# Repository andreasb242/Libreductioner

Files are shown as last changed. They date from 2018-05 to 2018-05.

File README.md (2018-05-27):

# Libreductioner
Induction loop sender for mower.

Tested and working with Landroid Worx. All Bugs in the Board are corrected with Version 1.1, all additional, no-needed Parts are removed.

# Forum Thread
Mikrocontroller.net: https://www.mikrocontroller.net/topic/451337 (German)

# Extension / Support for other mower
If you have another mower, or would like to improve the Board: Create a Pull request!

## Board / Circuit
The Board / Circuit is created with KiCad.

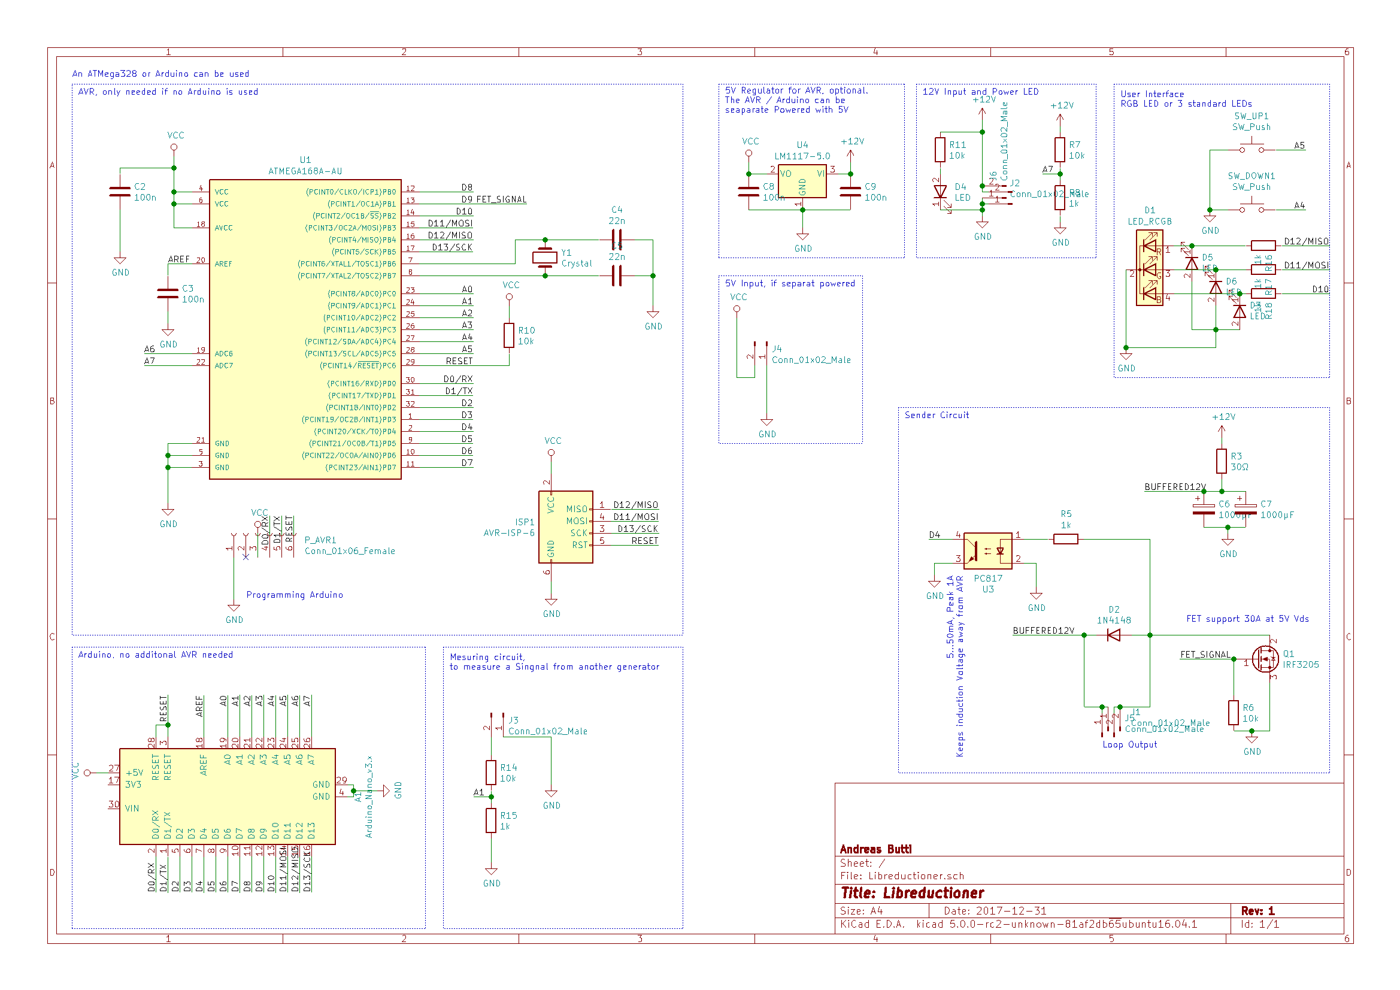
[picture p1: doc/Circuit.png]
Circuit

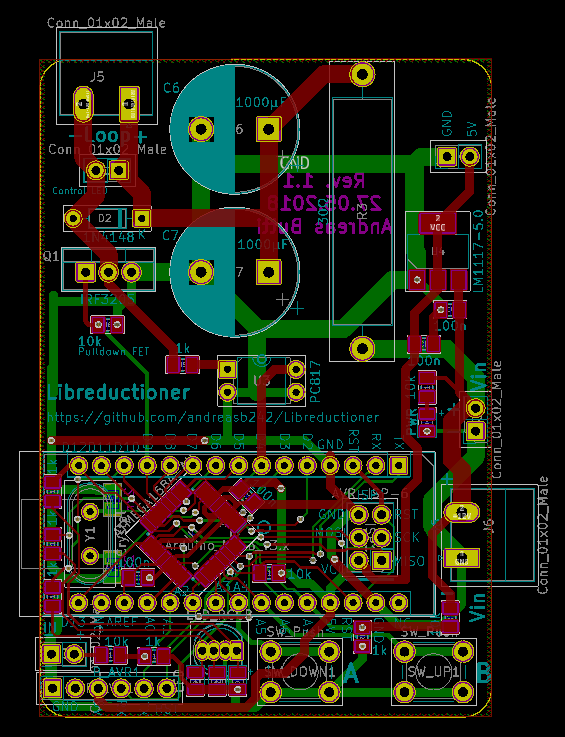
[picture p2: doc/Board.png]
Board

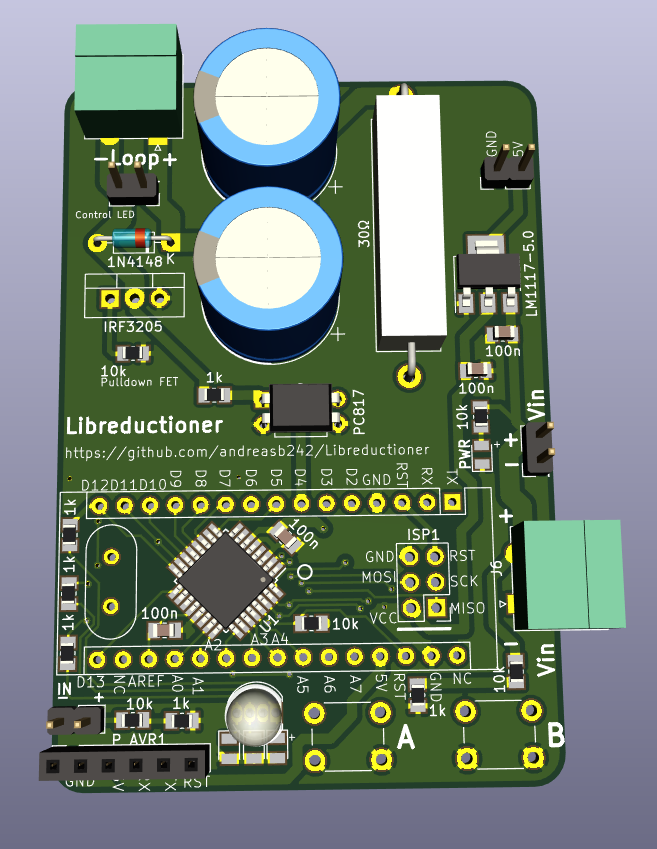
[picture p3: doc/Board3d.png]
Board


## Supported Mower
Currently working is the Landroid Worx

## Measuring
The Signal can be measured with a coil of a 24V Relais

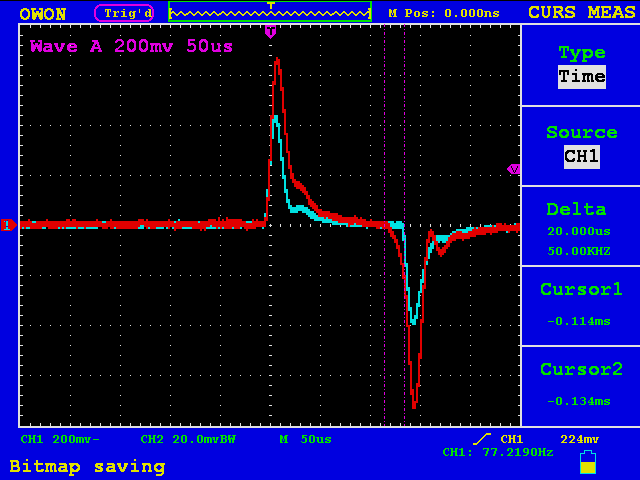
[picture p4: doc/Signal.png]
Signal Screenshot


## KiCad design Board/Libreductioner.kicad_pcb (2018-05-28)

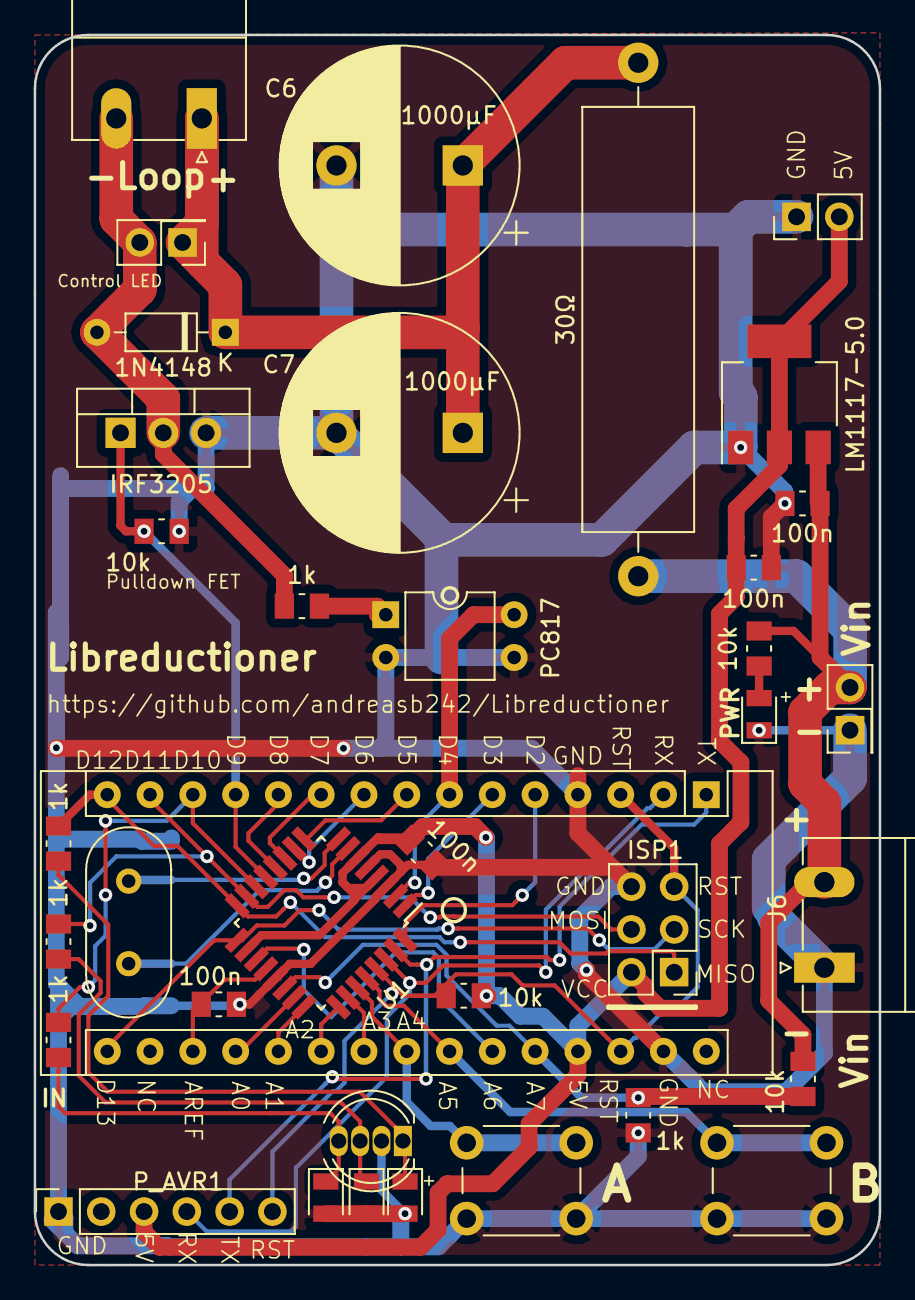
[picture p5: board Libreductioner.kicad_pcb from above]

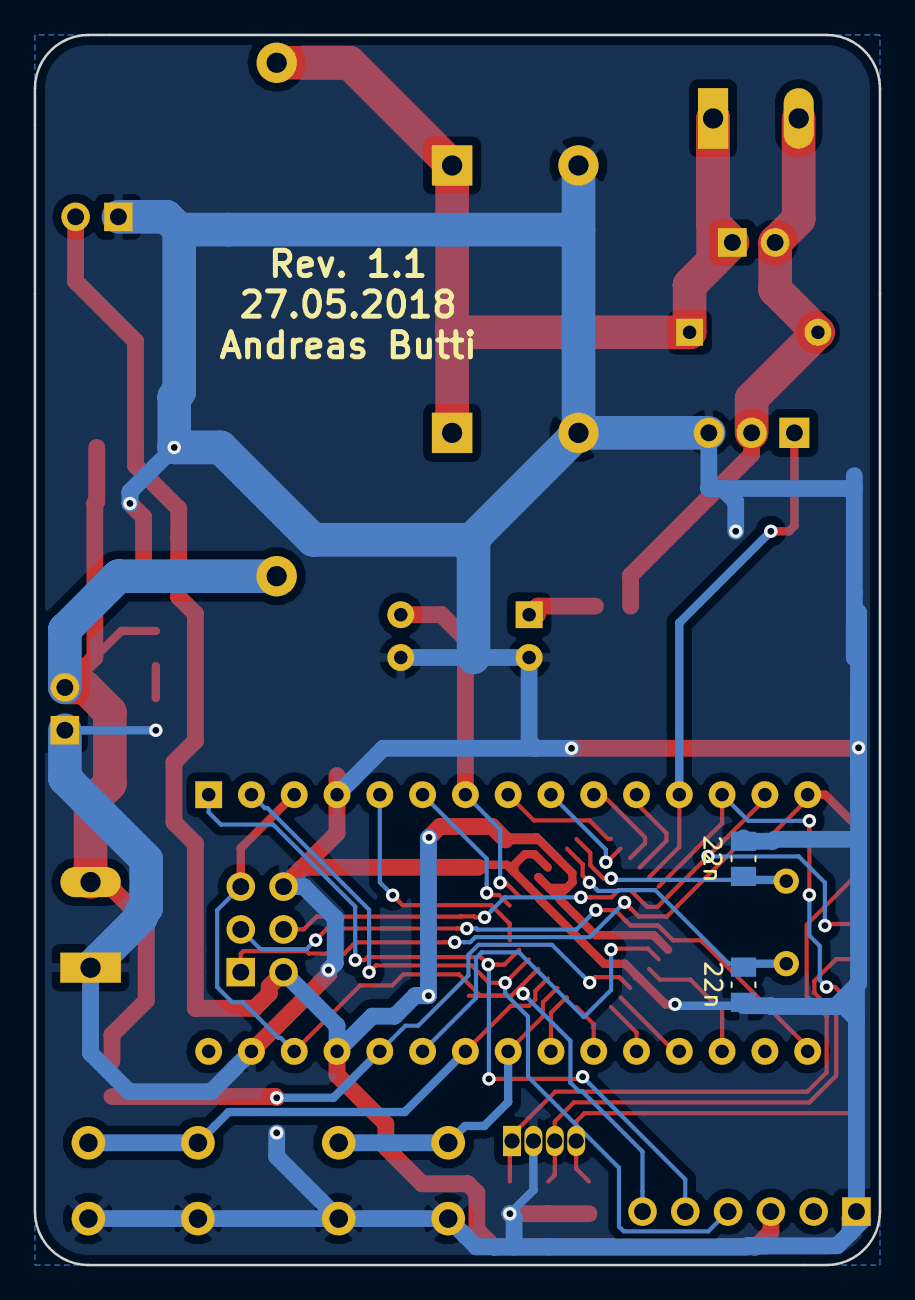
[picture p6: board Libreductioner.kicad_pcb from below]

Board: 2 copper layers, 50.2 x 73.0 mm, 39 parts (2 on the bottom side), 36 nets.

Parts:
A1: Arduino_Nano_v3.x; Arduino_Nano
C2, C3, C8, C9: 100n; C_0805_2012Metric_Pad1.15x1.50mm_HandSolder
C4, C5: 22n; C_0805_2012Metric_Pad1.15x1.50mm_HandSolder
C6, C7: 1000µF; CP_Radial_D14.0mm_P7.50mm
D1: LED_RCGB; LED_D5.0mm-4
D2: 1N4148; D_DO-35_SOD27_P7.62mm_Horizontal
D3, D4, D5, D6: LED; LED_0805_2012Metric_Pad0.97x1.50mm_HandSolder
ISP1: AVR-ISP-6; Pin_Header_Straight_2x03_Pitch2.54mm
J1, J2: Conn_01x02_Male; PinHeader_2x01_P2.54mm_Vertical
J4: Conn_01x02_Male; PinHeader_1x02_P2.54mm_Vertical
J5, J6: Conn_01x02_Male; PhoenixContact_MC_1,5_2-G-5.08_1x02_P5.08mm_Horizontal
P_AVR1: Conn_01x06_Female; PinSocket_1x06_P2.54mm_Vertical
Q1: IRF3205; TO-220-3_Vertical
R3: 30Ω; R_Axial_Power_L25.0mm_W6.4mm_P30.48mm
R5, R8, R16, R17, R18: 1k; R_0805_2012Metric_Pad1.15x1.50mm_HandSolder
R6, R7, R10, R11: 10k; R_0805_2012Metric_Pad1.15x1.50mm_HandSolder
SW_DOWN1: SW_Push; SW_PUSH_6mm_H8.5mm
SW_UP1: SW_Push; SW_PUSH_6mm_H8.5mm
U1: ATMEGA168A-AU; TQFP-32_7x7mm_P0.8mm
U3: PC817; DIP-4_W7.62mm
U4: LM1117-5.0; SOT-223-3_TabPin2
Y1: Crystal; Crystal_HC18-U_Vertical

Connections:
+12V: C9.1, J2.2, J6.2, R3.1, R7.1, R11.1, U4.3
/A0: A1.19, U1.23
/A1: A1.20, U1.24
/A2: A1.21, U1.25
/A3: A1.22, U1.26
/A4: A1.23, SW_DOWN1.2, U1.27
/A5: A1.24, SW_UP1.2, U1.28
/A6: A1.25, U1.19
/A7: A1.26, R7.2, R8.1, U1.22
/AREF: A1.18, C3.1, U1.20
/BUFFERED12V: C6.1, C7.1, D2.1, J1.1, J5.1, R3.2
/D0/RX: A1.2, P_AVR1.4, U1.30
/D1/TX: A1.1, P_AVR1.5, U1.31
/D2: A1.5, U1.32
/D3: A1.6, U1.1
/D4: A1.7, U1.2, U3.4
/D5: A1.8, U1.9
/D6: A1.9, U1.10
/D7: A1.10, U1.11
/D8: A1.11, U1.12
/D9: A1.12, Q1.1, R6.1, U1.13
/D10: A1.13, R18.1, U1.14
/D11/MOSI: A1.14, ISP1.4, R17.1, U1.15
/D12/MISO: A1.15, ISP1.1, R16.1, U1.16
/D13/SCK: A1.16, ISP1.3, U1.17
/RESET: A1.3, A1.28, ISP1.5, P_AVR1.6, R10.2, U1.29
GND: A1.4, A1.29, C2.2, C3.2, C4.1, C5.1, C6.2, C7.2, C8.2, C9.2, D1.2, D3.2, D4.1, D5.2, D6.2, ISP1.6, J2.1, J4.1, J6.1, P_AVR1.1, Q1.3, R6.2, R8.2, SW_DOWN1.1, SW_UP1.1, U1.3, U1.5, U1.21, U3.2, U3.3, U4.1
unnamed: C4.2, U1.7, Y1.1
unnamed: C5.2, U1.8, Y1.2
unnamed: D1.1, D5.1, R16.2
unnamed: D1.3, D6.1, R17.2
unnamed: D1.4, D3.1, R18.2
unnamed: D2.2, J1.2, J5.2, Q1.2, R5.2
unnamed: D4.2, R11.2
unnamed: R5.1, U3.1
VCC: A1.27, C2.1, C8.1, ISP1.2, J4.2, P_AVR1.3, R10.1, U1.4, U1.6, U1.18, U4.2

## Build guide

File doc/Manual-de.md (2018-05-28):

# Handbuch für Libreductioner

## LED Farben
blau: aufstarten / Kondensatoren aufladen. Dauert nur wenige Sekunden.
rot blinked: Kein Kabel angeschlossen
grün: Kabel angeschlossen, Signal wird gesendet

## Menu / Tasten
Libreductioner verfügt über ein kleines Menü, zum konfigurieren des Senders. Die Menüpunkt werden über Blinkcodes an die LED ausgegeben.

Durch das Hauptmenü wird navigiert mit der Taste A. Durch drücken der Taste B wird die Funktion gestartet, siehe weiter unten für die Beschreibung.
Durch drücken von A wird das Hauptmenü gestartet, die LED leuchte gelb. Das Signal wird nicht mehr gesendet.

* [türkis - grün] Signal / Hersteller wählen: Welches Signal wird gesendet
* [türkis - grün - grün] Entwickler Modus: Signale Testen
* [türkis - grün - grün - grün] Menü verlassen: Signal wird wider gesendet

## Signal / Hersteller wählen
Nach dem drücken der Taste B leuchtet die LED Violet. Durch drücken von A kann das Signal gewählt werden.
Der Hersteller wird durch ein gelbes Blinksignale ausgegeben:
1: Landroid Worx (Standard)
2: Husquarna Begrenzungssignal
3: Husquarna Leitsignal (der Rasenmäher folgt, ohne mähen)

Bestätigt wird durch langes drücken der Taste B (min 3 Sekunden), kurzes drücken der Taste B verlässt das Menü, ohne Einstellungen zu ändern.
Blinkt die LED grün: Die Wahl wurde gespeichert.
Blinkt die LED rot: Menü verlassen ohne zu speichern.

## Entwickler Modus
Bestätigen mit Taste B. Die Aufzeichnung beginnt, die LED leuchtet 3 mal kurz violet auf.
Das Menu wird verlassen.

## Menü verlassen
Bestätigen mit Taste B.
Das Menu wird verlassen.

## Serial Commands
Libreductioner kann über eine Serielle Schnittstelle mit einem PC Kommunizieren, z.B. über die Arduino IDE. 115200 Baud.
Es werden immer Informationen zum Status ausgegeben.

Zusätzlich können folgende Befehle gesendet werden: (Ein Befehl ist immer nur ein Zeichen)
d: Debugmessung wird gestartet, verschieden lange Signale werden gesendet, Mess Input wird angezeigt. Um Verbindungen / Aufbau zu testen.
p: Aufgezeichnete Signale werden ausgegeben.
r: Signal aufzeichen und direkt ausgeben

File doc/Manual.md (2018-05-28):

# User manual for Libreductioner

## LED Colors
blue: startup / charging capacitor. Takes only a few seconds.
red blinking: No cable connected
green: Cable connected, signal will be transmitted

## Menu / Button

TODO Work in progress

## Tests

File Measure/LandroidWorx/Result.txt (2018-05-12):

The red line is the self built sender. The blue one the original.

Measured with a coil of a 24V Relais.

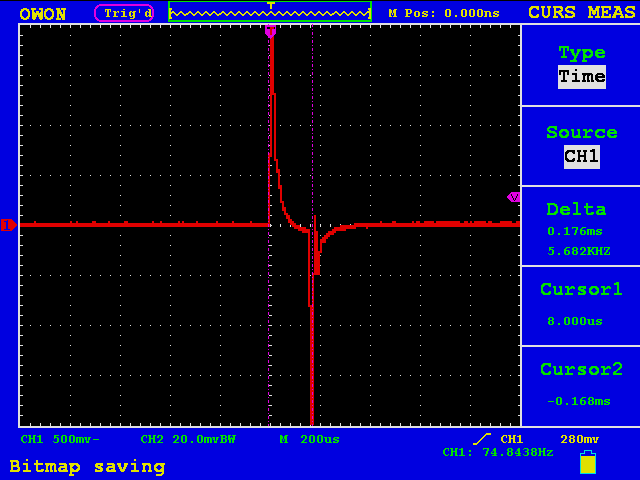
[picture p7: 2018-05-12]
Measure/LandroidWorx/Timing/01A.png

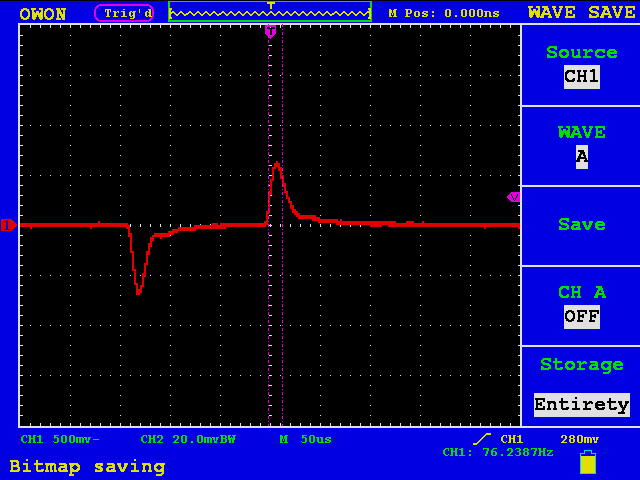
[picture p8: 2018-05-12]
Measure/LandroidWorx/Outside/00original.png

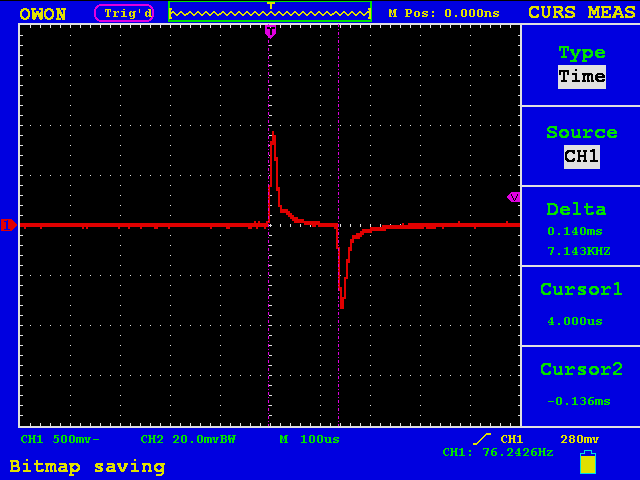
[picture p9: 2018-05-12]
Measure/LandroidWorx/Timing/00A-original.png

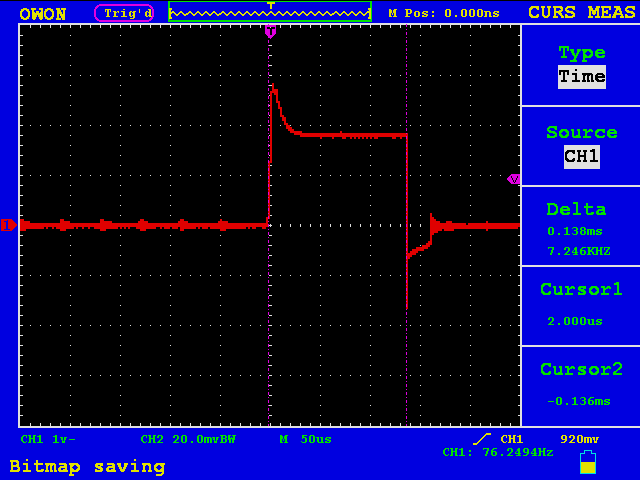
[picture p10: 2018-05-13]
Measure/LandroidWorx/OrignaloutputWihtoutLoop/Loop.png

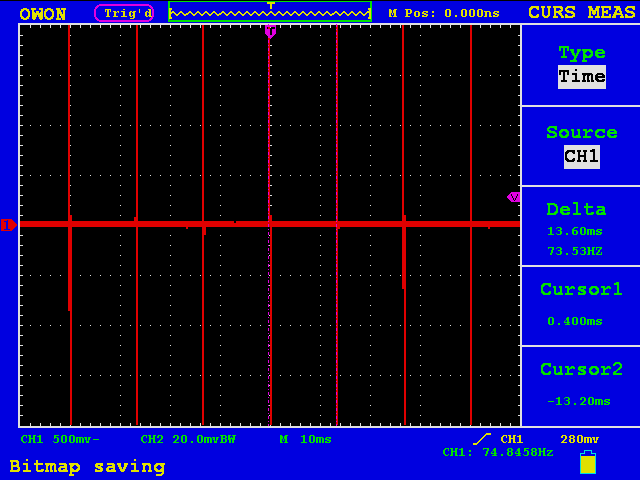
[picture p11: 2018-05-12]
Measure/LandroidWorx/Timing/01B.png

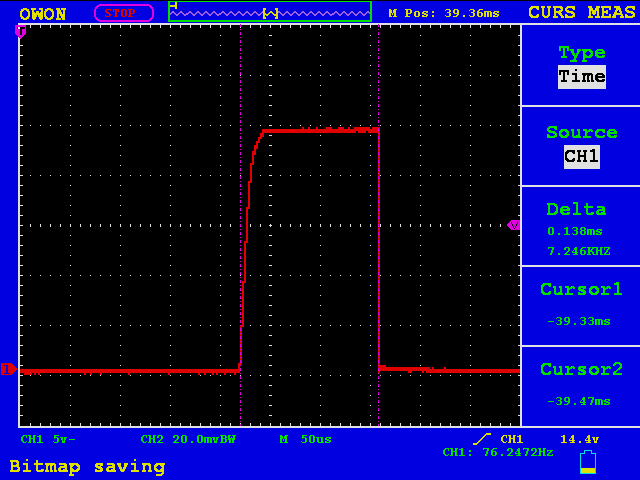
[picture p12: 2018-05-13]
Measure/LandroidWorx/OrignaloutputWihtoutLoop/Resistor.png

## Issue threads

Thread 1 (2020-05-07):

alternative charger

feiltom, 2020-05-07:
hello, my charger is dead and i use your board with a led driver for charging.
thank for all, all is ok my landroid come back to life ;)

i have adapt for command on jlpcb
https://easyeda.com/feiltom/libreductioner

i want to adapt for include charging section to the board. you say on forum 1w for 12v ?
this make 83ma ? on peak also ?
with lockdown i don t have access to my mesure device.
have a. good day.

andreasb242, 2020-05-07:
I don't know, I have to build a device again, as I have blow up mine with a Battery Pack, which goes up to 19V by pressing the Power button a short time, and long time to turn on / off.
I pressed to short, and it completely blew up...

feiltom, 2020-05-07:
thank you,
i make the current mesure in 2 week.
do you want have the result ?
you can close the issue.
thank you for your job.

andreasb242, 2020-05-07:
Yes, if you have the result, post it here, because somebody may find this, because of the same question ;-)

feiltom, 2020-07-03:
Hello, i don't have the result, no amp meter, i work again in remote.
all works for me now.
My work is here : https://github.com/feiltom/LibreWorx.
I can send you a board as thank for your job?
I make current mesure as soon as possible.

andreasb242, 2020-07-06:
Hi

      Thanks for the Feedback!
      From where are you? Depending on
        this, the shipping might cost more than the Board...

      I would be much more interested in
        images, you added Charging, did you already build a case /
        connectors?

      By the way I use mine battery
        Powered, therefore Charging is no option ;-)

      My Email Address / I thought this is
        public anyway... But github uses Some anonymize address...:
      andreas_b123@bluewin.ch

      Andreas

    Am 03.07.20 um 23:53 schrieb Thomas
      FEILLANT:

      Hello, i don't have the result, no amp meter, i work again in
        remote.
        all works for me now.
        My work is here : https://github.com/feiltom/LibreWorx.
        I can send you a board as thank for your job?
        I make current mesure as soon as possible.
      —
        You are receiving this because you commented.
        Reply to this email directly, view it on GitHub, or unsubscribe.
      [
{
"@context": "http://schema.org",
"@type": "EmailMessage",
"potentialAction": {
"@type": "ViewAction",
"target": "https://github.com/andreasb242/Libreductioner/issues/1#issuecomment-653684425",
"url": "https://github.com/andreasb242/Libreductioner/issues/1#issuecomment-653684425",
"name": "View Issue"
},
"description": "View this Issue on GitHub",
"publisher": {
"@type": "Organization",
"name": "GitHub",
"url": "https://github.com"
}
}
]

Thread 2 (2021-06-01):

Verkauf von Modulen

hyper2910, 2021-06-01:
Hi,

Verkaufst du auch deine Module?

andreasb242, 2021-06-01:
Nein, habe ich nicht vor.
Das Board kriegst du recht günstig, z.B. auf JLCPCB, aber bestücken musst du selbst, leider bestücken die weder die Leistungswiderstände noch die grossen Kondensatoren...

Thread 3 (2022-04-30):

Temporäre Begrenzungsschleife Husqvarna/Gardena

DpunktS, 2022-04-30:
Hallo,

kann deine Begrenzungsschleife bei jeden Husqvarna Mäher ohne neu anlernen verwendet werden. Also zusätzlich zu der Originalen. Oder ist es möglich das vorhandene Signal zu klonen.
Muss dein Modul mit 12v betrieben werden oder geht auch 5v.

Zur Erklärung ich habe einen Gardena Sileno Life (Husqvarna) und würde gern eine oder mehrere temporäre Begrenzungsschleifen realisieren.

Gardena bietet ab Sommer 2022 so etwas an (wird bestimmt nicht billig). Bei dem letzten Software Update ist diese Funktion schon enthalten. https://www.gardena.com/es/productos/cuidado-del-cesped/robot-cortacesped/zoneprotect/970525601/

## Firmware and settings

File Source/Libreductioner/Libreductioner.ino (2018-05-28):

/**
 * Libreductioner
 * Sender Unit for Worx Landroid and other Mower
 * 
 * (c) Andreas Butti, 2018
 * andreasbutti at gmail dot com
 * 
 * License: GPL
 */

/**
 * Hardware:
 * See the Board circuit
 */

#include "UI.h"
#include "SignalOutput.h"
#include "Menu.h"

/**
 * Last state, to log changes
 */
uint8_t g_lastCableConnected = 0;

/**
 * Setup IO
 */
void setup() {
  ui.setup();

  Serial.begin(115200);
  Serial.println("Libreductioner, (c) Andreas Butti, 2018");
  Serial.println("https://github.com/andreasb242/Libreductioner");

  // Some time for capacitor to charge
  delay(3000);

  signalOutput.setup();
  signalOutput.start();
}

/**
 * Main Loop
 */
void loop() {
  if (ui.loop()) {
    signalOutput.stop();
    menu.loop();
    signalOutput.start();

    // Update LED on next loop iteration
    g_lastCableConnected = 0;
  }

  if (Serial.available()) {
    char c = Serial.read();
    if ('d' == c) {
      // Selfcheck / Output and loop input test
      menu.debugRun();
    }
  }

  if (signalOutput.isCableConnected()) {
    if (g_lastCableConnected != 1) {
      ui.setLed(LED_C_GREEN);
      g_lastCableConnected = 1;
      Serial.println("Cable connected");
    }
  } else {
    if (g_lastCableConnected != 2) {
      ui.setLed(LED_C_RED_BLINK);
      g_lastCableConnected = 2;
      Serial.println("Cable disconnected");
    }
  }
}

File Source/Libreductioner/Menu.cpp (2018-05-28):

/**
 * Libreductioner
 * Sender Unit for Worx Landroid and other Mower
 * 
 * (c) Andreas Butti, 2018
 * andreasbutti at gmail dot com
 * 
 * License: GPL
 */

#include "Menu.h"
#include "UI.h"
#include "SignalOutput.h"

/**
 * Single instance of Menu
 */
Menu menu;

/**
 * Constructor
 */
Menu::Menu() {
}

/**
 * Loop call for menu
 */
void Menu::loop() {
  Serial.println("> Enter menu");

  m_menuPos = 0;
  outputMenuPosition();

  while (true) {
    if(step()) {
      break;
    }
  }
  
  Serial.println("< Leave menu");
}

/**
 * Output menu position
 */
void Menu::outputMenuPosition() {
  ui.setLed(LED_C_WHITE);
  delay(500);
  ui.setLed(LED_C_OFF);
  delay(100);

  if (m_menuPos == 0) {
    Serial.println("-> Select Device");
  } else if (m_menuPos == 1) {
    Serial.println("-> Developer mode");
  } else if (m_menuPos == 2) {
    Serial.println("-> Exit");
  }

  for (uint8_t i = 0; i <= m_menuPos; i++) {
    ui.setLed(LED_C_GREEN);
    delay(500);
    ui.setLed(LED_C_OFF);
    delay(100);
  }

  delay(500);

  // Block until the key is released...
  while(ui.isButtonADown()) {
    // wait for key down
  }
  delay(5);


  ui.setLed(LED_C_YELLOW);
}

/**
 * Run a single debug run
 */
void Menu::debugRun() {
  Serial.println("Debug Run: -------------------------------------------------------");

  uint8_t values[200];

  for (uint8_t i = 1; i <= 100; i++) {
    Serial.println("--------------------");
    Serial.print("Run ");
    Serial.println(i);

    signalOutput.write(true);
    for (uint8_t u = 0; u < 200; u++) {
      delayMicroseconds(2);
      if (u == i) {
        signalOutput.write(false);
      }
      values[u] = signalOutput.read();
    }

    signalOutput.write(false);

    for (uint8_t u = 0; u < 200; u++) {
      if (u == i) {
        Serial.print(" OFF");
      }
      if (u % 10 == 0) {
        Serial.print("\n");
        if (u < 10) {
          Serial.print("0");
        }
        if (u < 100) {
          Serial.print("0");
        }
        Serial.print(u);
        Serial.print(":");
      }
      Serial.print(" ");
      Serial.print(values[u]);
    }
    Serial.print("\n");
  }

  Serial.println("------------------------------------------------------------------");
}

/**
 * Debug menu
 */
void Menu::debug() {
  while (true) {
    ui.setLed(LED_C_CYAN);

    if (ui.isButtonADown()) {
      delay(5);
      while(ui.isButtonADown());
      delay(5);

      ui.setLed(LED_C_YELLOW);

      debugRun();
    }


    if (ui.isButtonBDown()) {
      break;
    }
  }

  ui.setLed(LED_C_OFF);
}

/**
 * Select output signal
 */
void Menu::selectSignal() {
  ui.setLed(LED_C_VIOLET);

  uint8_t signalId = 0;

  while (true) {
    if (ui.isButtonADown()) {
      ui.setLed(LED_C_OFF);

      delay(5);
      while (ui.isButtonADown());
      delay(5);

      signalId++;

      if (signalId > 3) {
        signalId = 1;
      }

      for (uint8_t i = 0; i < signalId; i++) {
        ui.setLed(LED_C_YELLOW);
        delay(500);
        ui.setLed(LED_C_OFF);
        delay(100);
      }

      delay(500);
      ui.setLed(LED_C_VIOLET);
    }

    if (ui.isButtonBDown()) {
      ui.setLed(LED_C_OFF);

      unsigned long start = millis();
      delay(5);
      while (ui.isButtonBDown());
      delay(5);

      if ((millis() - start) >= 3000) {
        Serial.println("Stored");
        ui.setLed(LED_C_GREEN);
      } else {
        Serial.println("Not stored");
        ui.setLed(LED_C_RED);
      }

      delay(1000);
      ui.setLed(LED_C_OFF);
      delay(1000);
      return;
    }    
  }
}

/**
 * Execute a menu step
 */
bool Menu::step() {
  if (ui.isButtonBDown()) {
    delay(5);
    while(ui.isButtonBDown());
    delay(5);

    Serial.print("Confirm menu ");
    Serial.println(m_menuPos);

    if (m_menuPos == 0) {
      selectSignal();
      return true;
    } else if (m_menuPos == 1) {
      // TODO Developer mode
      return true;
    } else if (m_menuPos == 2) {
      // Exit
      return true;
    }
  }

  if (ui.isButtonADown()) {
    m_menuPos++;
    if (m_menuPos >= 3) {
      m_menuPos = 0;
    }
    outputMenuPosition();
  }

  return false;
}

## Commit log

2018-05-13 Board optimized
    [Libreductioner.kicad_pcb, Libreductioner.sch]
2018-05-13 Board optimisations
    [Libreductioner.kicad_pcb, Libreductioner.sch]
2018-05-13 Optimized Board
    [Libreductioner.kicad_pcb, Libreductioner.sch]
2018-05-13 Improved Board
    [Libreductioner.kicad_pcb]
2018-05-13 Added gerber files for production
    [Libreductioner-B.Cu.gbr, Libreductioner-B.Mask.gbr, Libreductioner-B.SilkS.gbr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]
2018-05-22 Pinout adapted to board
2018-05-22 Fixed wrong description on Power Plug
    [Libreductioner.kicad_pcb]
2018-05-26 Fixed layout bugs found on Testing
    [Libreductioner-B.Cu.gbr, Libreductioner-B.Mask.gbr, Libreductioner-B.SilkS.gbr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]
2018-05-27 Board Cleanup, removed all non-needed parts
    [Libreductioner.kicad_pcb, Libreductioner.sch]
2018-05-27 Updated Board Screenshots
2018-05-28 Removed Input: AVR is to slow for measuring the signal precise enough
    [Libreductioner.kicad_pcb, Libreductioner.sch]
